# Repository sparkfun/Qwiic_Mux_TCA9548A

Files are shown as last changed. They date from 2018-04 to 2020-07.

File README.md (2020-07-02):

SparkFun Qwiic Mux Breakout - 8 Channel (TCA9548A)
========================================

SparkFun Qwiic Mux Breakout - 8 Channel (TCA9548A)

[*SparkFun Qwiic Mux Breakout - 8 Channel (TCA9548A) (BOB-16784)*](https://www.sparkfun.com/products/16784)

The Qwiic Mux Breakout enables communication with multiple I2C devices that have the same address and gets them all talking on the same bus! The Qwiic Mux also has eight configurable addresses of its own, allowing for up to 64 I2C buses on a connection. To make it even easier to use this multiplexer, all communication is enacted exclusively via I2C, utilizing our handy Qwiic system.

Repository Contents
-------------------

* **/Firmware** - Example code 
* **/Hardware** - Eagle design files (.brd, .sch)
* **/Production** - Production panel files (.brd)

Documentation
--------------
* **[Hookup Guide](https://learn.sparkfun.com/tutorials/qwiic-mux-hookup-guide)** - Basic hookup guide for the SparkFun Qwiic Mux TCA9548A.

Product Versions
----------------
* [BOB-16784](https://www.sparkfun.com/products/16784) - Version 1.1 (added pass-through Qwiic connector)
* [BOB-14685](https://www.sparkfun.com/products/14685)- SparkFun red version with TCA9548A
* [SPX-14293](https://www.sparkfun.com/products/14293)- SparkX version with PCA9548A

License Information
-------------------

This product is _**open source**_! 

Please review the LICENSE.md file for license information. 

If you have any questions or concerns on licensing, please contact techsupport@sparkfun.com.

Distributed as-is; no warranty is given.

- Your friends at SparkFun.

_<COLLABORATION CREDIT>_

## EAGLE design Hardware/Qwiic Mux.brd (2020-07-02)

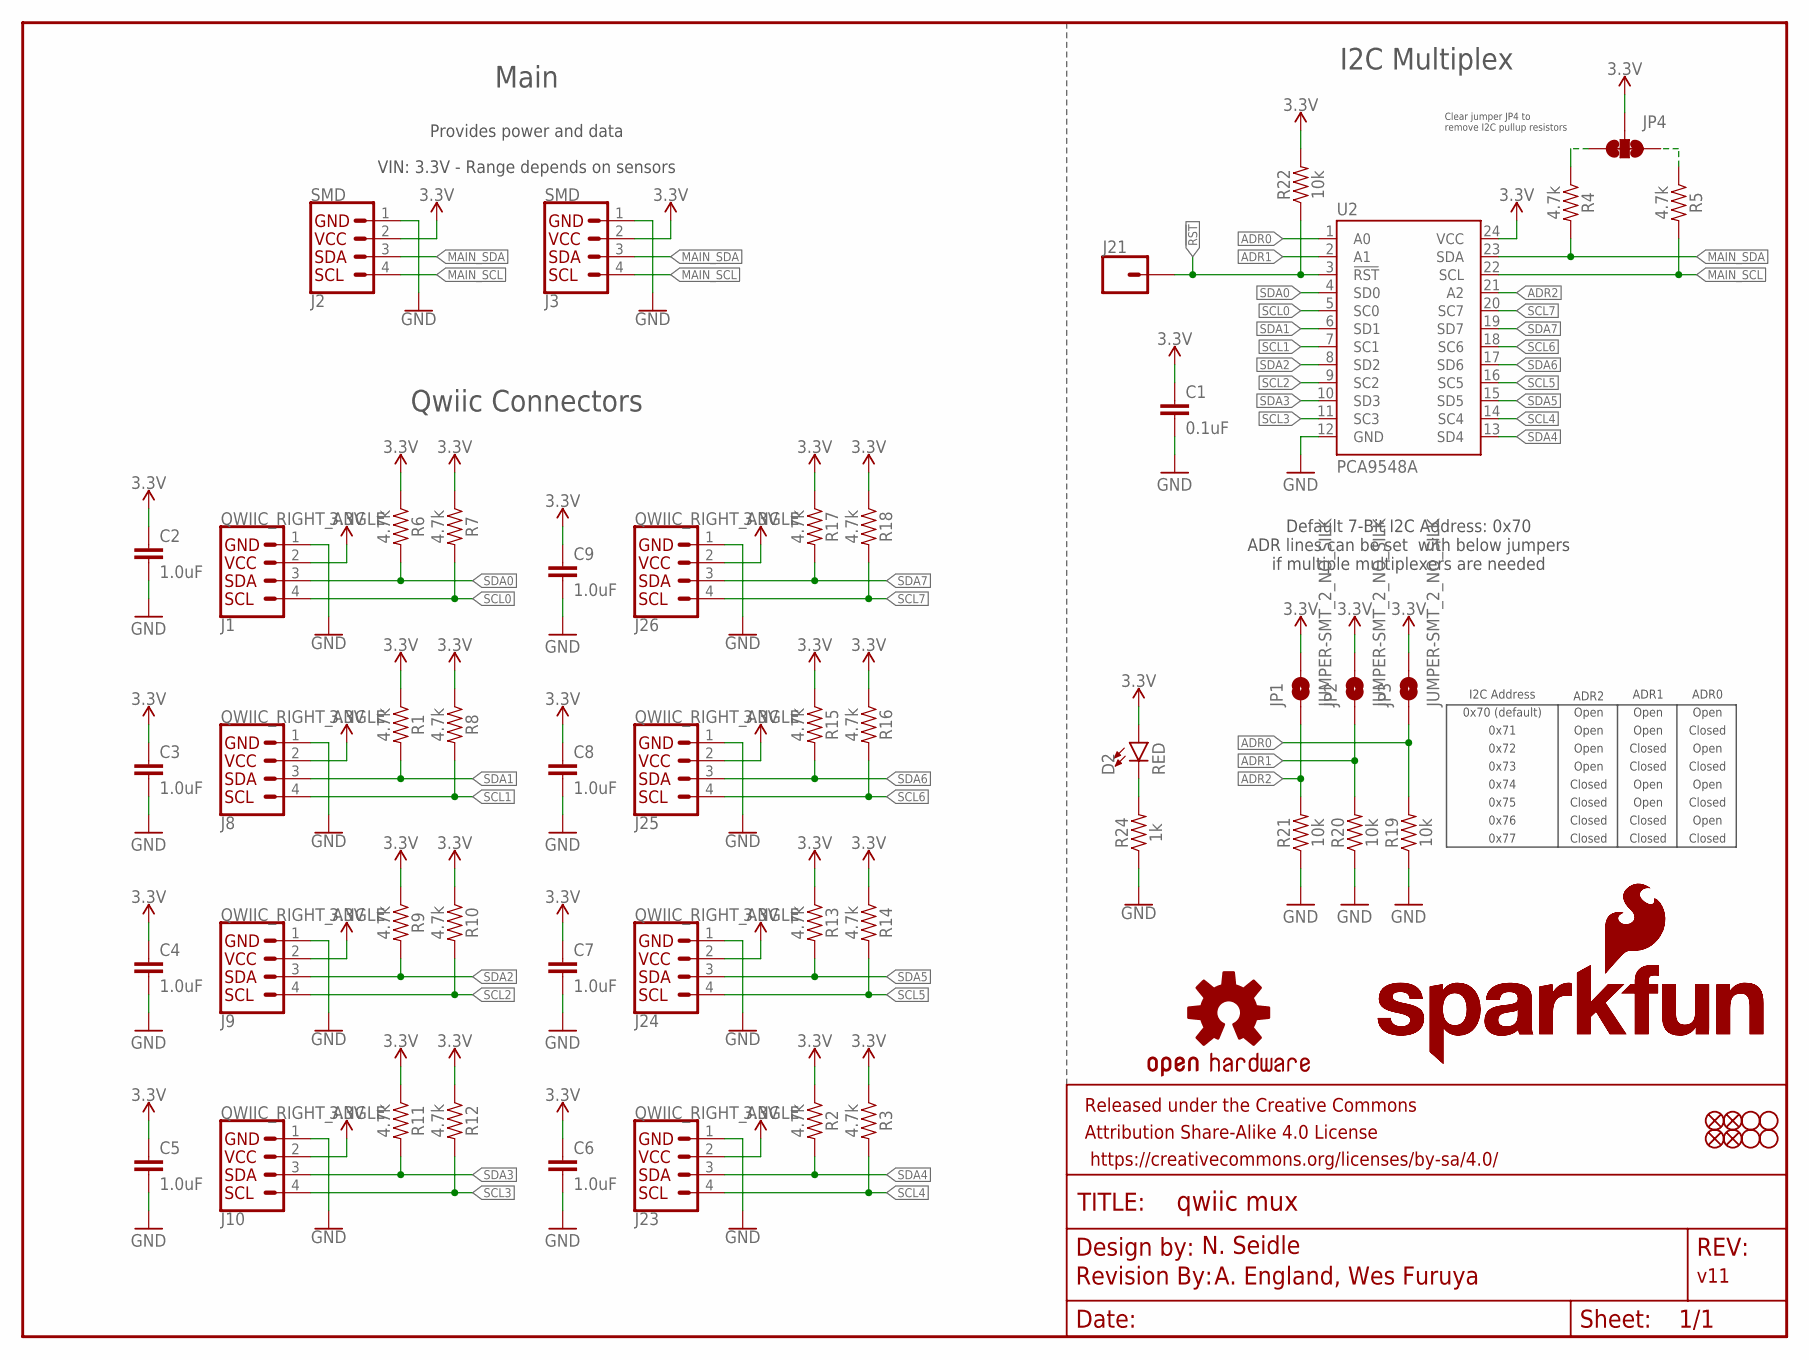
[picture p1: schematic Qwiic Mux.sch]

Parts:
C1: 0.1uF; 0603
C2, C3, C4, C5, C6, C7, C8, C9: 1.0uF; 0603
D2: RED; LED-0603
FD1, FD2, FD3, FD4: FIDUCIAL1X2; FIDUCIAL-1X2
FRAME1: FRAME-LETTER; CREATIVE_COMMONS
H1, H2, H3, H4: STAND-OFF
J1, J8, J9, J10, J23, J24, J25, J26: QWIIC_RIGHT_ANGLE; JST04_1MM_RA
J2, J3: SMD; 1X04_1MM_RA
J21: CONN_01PTH_NO_SILK_YES_STOP; 1X01_NO_SILK
JP1, JP2, JP3: JUMPER-SMT_2_NO_SILK; SMT-JUMPER_2_NO_SILK
JP4: JUMPER-SMT_3_2-NC_TRACE_SILK; SMT-JUMPER_3_2-NC_TRACE_SILK
LOGO1: OSHW-LOGOMINI; OSHW-LOGO-MINI
LOGO2: REVISION
R1, R2, R3, R4, R5, R6, R7, R8, R9, R10, R11, R12, R13, R14, R15, R16, R17, R18: 4.7k; 0603
R19, R20, R21, R22: 10k; 0603
R24: 1k; 0603
U2: PCA9548A; TSSOP28
U$1, U$2: SFE_LOGO_NAME_FLAME.1_INCH; SFE_LOGO_NAME_FLAME_.1

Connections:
3.3V: C1.1, C2.1, C3.1, C4.1, C5.1, C6.1, C7.1, C8.1, C9.1, D2.A, J1.2, J2.2 (VCC), J3.2 (VCC), J8.2, J9.2, J10.2, J23.2, J24.2, J25.2, J26.2, JP1.2, JP2.2, JP3.2, JP4.2, R1.1, R2.1, R3.1, R6.1, R7.1, R8.1, R9.1, R10.1, R11.1, R12.1, R13.1, R14.1, R15.1, R16.1, R17.1, R18.1, R22.2, U2.24 (VCC)
!RST: J21.1, R22.1, U2.3 (!RST)
ADR0: JP3.1, R19.2, U2.1 (A0)
ADR1: JP2.1, R20.2, U2.2 (A1)
ADR2: JP1.1, R21.2, U2.21 (A2)
GND: C1.2, C2.2, C3.2, C4.2, C5.2, C6.2, C7.2, C8.2, C9.2, J1.1, J2.1 (GND), J3.1 (GND), J8.1, J9.1, J10.1, J23.1, J24.1, J25.1, J26.1, R19.1, R20.1, R21.1, R24.1, U2.12 (GND)
MAIN_SCL: J2.4 (SCL), J3.4 (SCL), R5.2, U2.22 (SCL)
MAIN_SDA: J2.3 (SDA), J3.3 (SDA), R4.2, U2.23 (SDA)
unnamed: D2.C, R24.2
unnamed: JP4.3, R4.1
unnamed: JP4.1, R5.1
SCL0: J1.4, R7.2, U2.5 (SC0)
SCL1: J8.4, R8.2, U2.7 (SC1)
SCL2: J9.4, R10.2, U2.9 (SC2)
SCL3: J10.4, R12.2, U2.11 (SC3)
SCL4: J23.4, R3.2, U2.14 (SC4)
SCL5: J24.4, R14.2, U2.16 (SC5)
SCL6: J25.4, R16.2, U2.18 (SC6)
SCL7: J26.4, R18.2, U2.20 (SC7)
SDA0: J1.3, R6.2, U2.4 (SD0)
SDA1: J8.3, R1.2, U2.6 (SD1)
SDA2: J9.3, R9.2, U2.8 (SD2)
SDA3: J10.3, R11.2, U2.10 (SD3)
SDA4: J23.3, R2.2, U2.13 (SD4)
SDA5: J24.3, R13.2, U2.15 (SD5)
SDA6: J25.3, R15.2, U2.17 (SD6)
SDA7: J26.3, R17.2, U2.19 (SD7)

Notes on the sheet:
N. Seidle
v11
Qwiic Connectors
Default 7-Bit I2C Address: 0x70 ADR lines can be set with below jumpers if multiple multiplexers are needed
Main
Provides power and data
VIN: 3.3V - Range depends on sensors
I2C Multiplex
I2C Address
ADR0
ADR1
ADR2
Open
Closed
0x70 (default)
0x71
0x72
0x73
0x74
0x75
0x76
0x77
A. England, Wes Furuya
Clear jumper JP4 to remove I2C pullup resistors

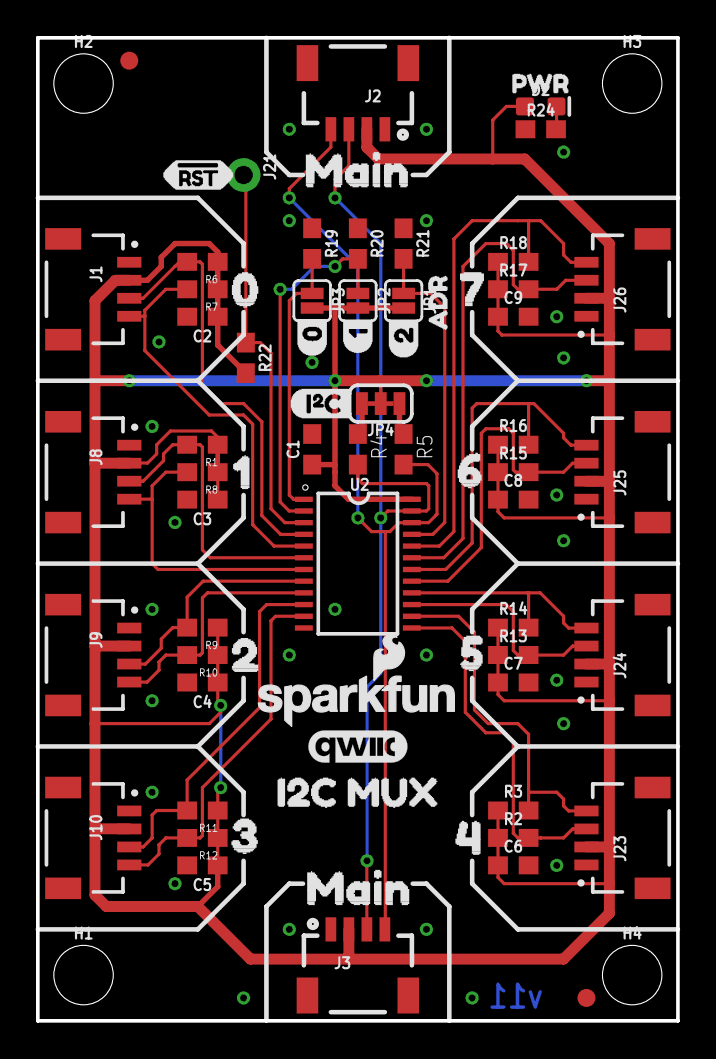
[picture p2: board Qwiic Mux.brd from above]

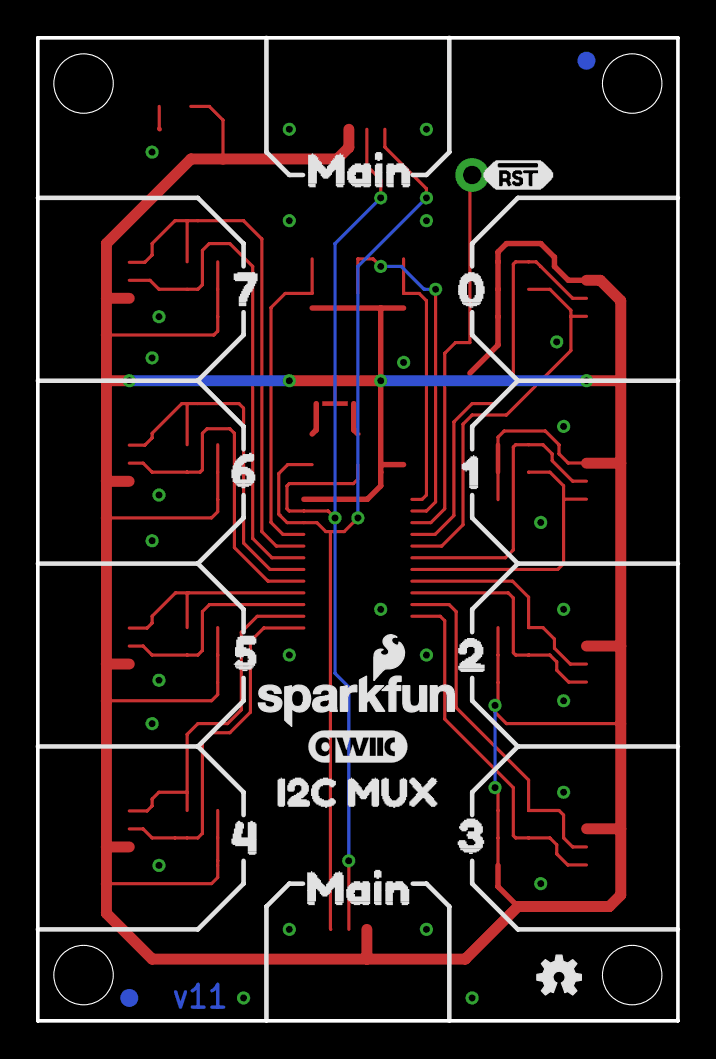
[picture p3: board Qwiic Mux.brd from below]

Board: 2 copper layers, 35.6 x 54.6 mm, 94 parts (17 on the bottom side), 27 nets.

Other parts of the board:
U$3, U$15: I2C_MUX8
U$4, U$36: QWIIC_5.5MM
U$5: 04
U$6, U$12: 00
U$7, U$18: 11
U$8, U$19: 22
U$9, U$20: 33
U$10, U$21: 44
U$11, U$22: 55
U$13, U$24: 77
U$14, U$26: !RST_I
U$16, U$25, U$27, U$28: MAIN0
U$17, U$23: 61
U$31: PWR_TO
U$32: 15
U$33: 26
U$34: ADR3
U$35: I#C6

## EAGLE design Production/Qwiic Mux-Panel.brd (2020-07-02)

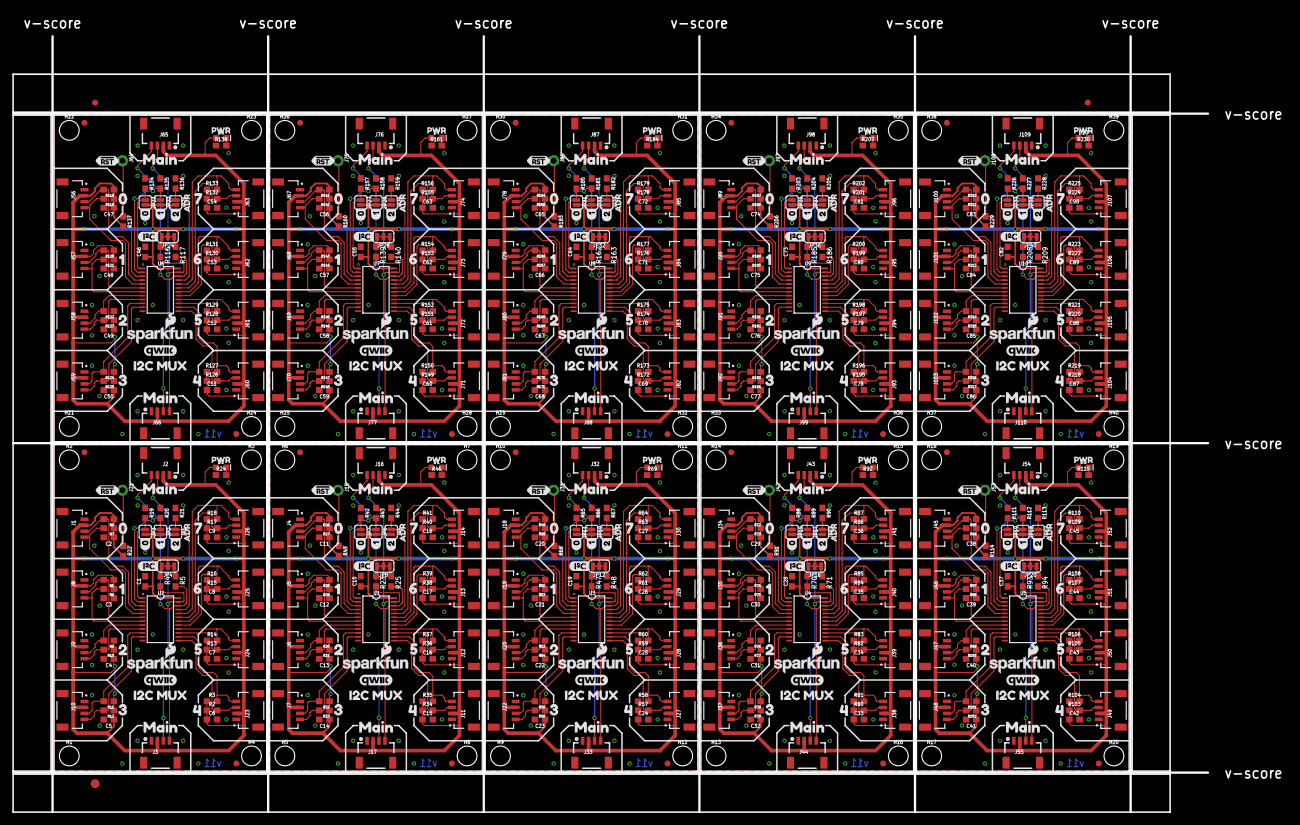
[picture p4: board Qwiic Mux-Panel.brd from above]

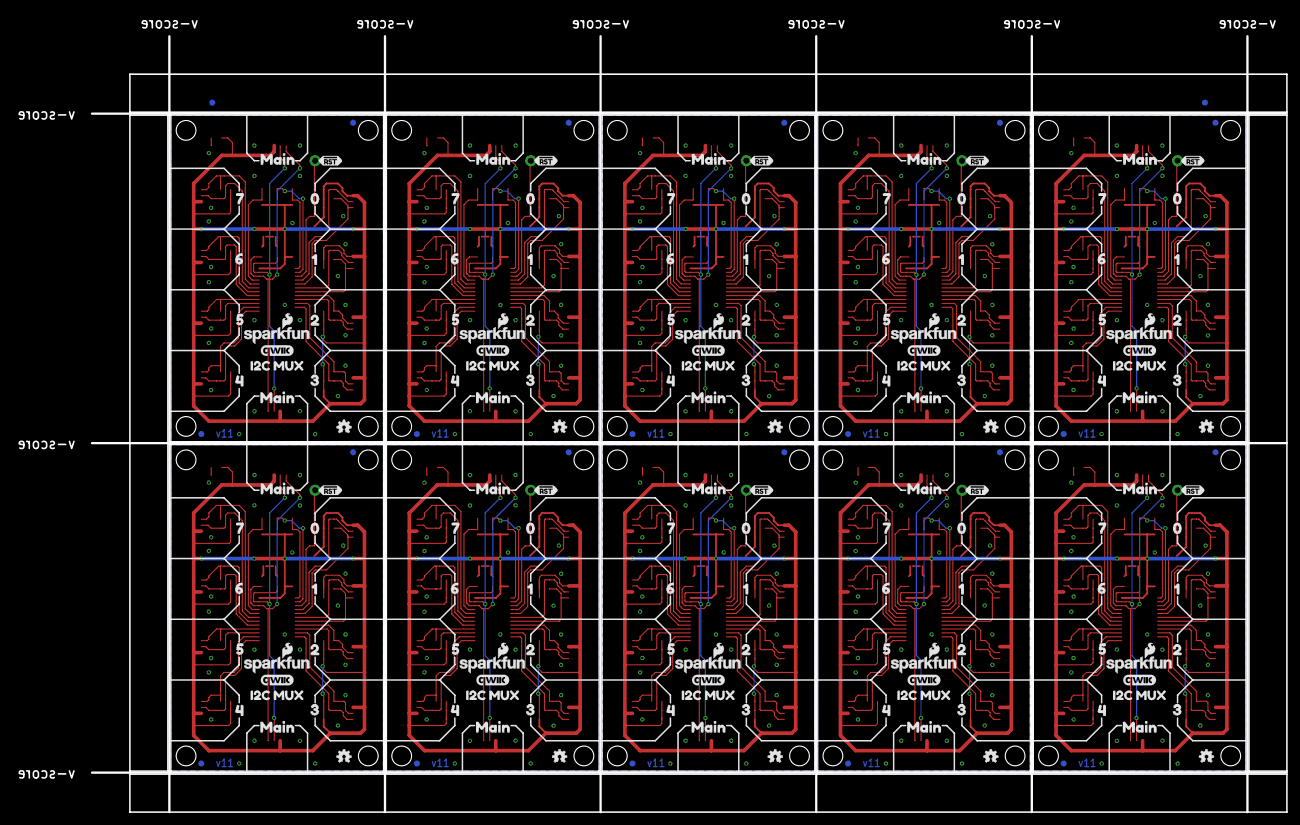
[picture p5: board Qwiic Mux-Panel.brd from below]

Board: 2 copper layers, 199.9 x 129.8 mm, 935 parts (172 on the bottom side), 270 nets.

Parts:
C1, C10, C19, C28, C37, C46, C55, C64, C73, C82: 0.1uF; 0603
C2, C3, C4, C5, C6, C7, C8, C9, C11, C12, C13, C14, C15, C16, C17, C18, C20, C21, C22, C23, C24, C25, C26, C27, C29, C30, C31, C32, C33, C34, C35, C36, C38, C39, C40, C41, C42, C43, C44, C45, C47, C48, C49, C50, C51, C52, C53, C54, C56, C57, C58, C59, C60, C61, C62, C63, C65, C66, C67, C68, C69, C70, C71, C72, C74, C75, C76, C77, C78, C79, C80, C81, C83, C84, C85, C86, C87, C88, C89, C90: 1.0uF; 0603
D1, D2, D3, D4, D5, D6, D7, D8, D9, D10: RED; LED-0603
E$1, E$2, E$3, E$4: FIDUCIAL-1X2
E$5: FIDUCIAL-1.5X3
FD1, FD2, FD3, FD4, FD5, FD6, FD7, FD8, FD9, FD10, FD11, FD12, FD13, FD14, FD15, FD16, FD17, FD18, FD19, FD20, FD21, FD22, FD23, FD24, FD25, FD26, FD27, FD28, FD29, FD30, FD31, FD32, FD33, FD34, FD35, FD36, FD37, FD38, FD39, FD40: FIDUCIAL1X2; FIDUCIAL-1X2
H1, H2, H3, H4, H5, H6, H7, H8, H9, H10, H11, H12, H13, H14, H15, H16, H17, H18, H19, H20, H21, H22, H23, H24, H25, H26, H27, H28, H29, H30, H31, H32, H33, H34, H35, H36, H37, H38, H39, H40: STAND-OFF
J1, J4, J5, J6, J7, J8, J9, J10, J11, J12, J13, J14, J18, J19, J20, J22, J23, J24, J25, J26, J27, J28, J29, J30, J34, J35, J36, J37, J38, J39, J40, J41, J45, J46, J47, J48, J49, J50, J51, J52, J56, J57, J58, J59, J60, J61, J62, J63, J67, J68, J69, J70, J71, J72, J73, J74, J78, J79, J80, J81, J82, J83, J84, J85, J89, J90, J91, J92, J93, J94, J95, J96, J100, J101, J102, J103, J104, J105, J106, J107: QWIIC_RIGHT_ANGLE; JST04_1MM_RA
J2, J3, J16, J17, J32, J33, J43, J44, J54, J55, J65, J66, J76, J77, J87, J88, J98, J99, J109, J110: SMD; 1X04_1MM_RA
J15, J21, J31, J42, J53, J64, J75, J86, J97, J108: 1X01_NO_SILK
JP1, JP2, JP3, JP5, JP6, JP7, JP9, JP10, JP11, JP13, JP14, JP15, JP17, JP18, JP19, JP21, JP22, JP23, JP25, JP26, JP27, JP29, JP30, JP31, JP33, JP34, JP35, JP37, JP38, JP39: JUMPER-SMT_2_NO_SILK; SMT-JUMPER_2_NO_SILK
JP4, JP8, JP12, JP16, JP20, JP24, JP28, JP32, JP36, JP40: JUMPER-SMT_3_2-NC_TRACE_SILK; SMT-JUMPER_3_2-NC_TRACE_SILK
LOGO1, LOGO3, LOGO5, LOGO7, LOGO9, LOGO11, LOGO13, LOGO15, LOGO17, LOGO19: OSHW-LOGOMINI; OSHW-LOGO-MINI
LOGO2, LOGO4, LOGO6, LOGO8, LOGO10, LOGO12, LOGO14, LOGO16, LOGO18, LOGO20: REVISION
R1, R2, R3, R4, R5, R6, R7, R8, R9, R10, R11, R12, R13, R14, R15, R16, R17, R18, R23, R25, R26, R27, R28, R29, R30, R31, R32, R33, R34, R35, R36, R37, R38, R39, R40, R41, R47, R48, R49, R50, R51, R52, R53, R54, R55, R56, R57, R58, R59, R60, R61, R62, R63, R64, R70, R71, R72, R73, R74, R75, R76, R77, R78, R79, R80, R81, R82, R83, R84, R85, R86, R87, R93, R94, R95, R96, R97, R98, R99, R100, R101, R102, R103, R104, R105, R106, R107, R108, R109, R110, R116, R117, R118, R119, R120, R121, R122, R123, R124, R125, R126, R127, R128, R129, R130, R131, R132, R133, R139, R140, R141, R142, R143, R144, R145, R146, R147, R148, R149, R150, R151, R152, R153, R154, R155, R156, R162, R163, R164, R165, R166, R167, R168, R169, R170, R171, R172, R173, R174, R175, R176, R177, R178, R179, R185, R186, R187, R188, R189, R190, R191, R192, R193, R194, R195, R196, R197, R198, R199, R200, R201, R202, R208, R209, R210, R211, R212, R213, R214, R215, R216, R217, R218, R219, R220, R221, R222, R223, R224, R225: 4.7k; 0603
R19, R20, R21, R22, R42, R43, R44, R45, R65, R66, R67, R68, R88, R89, R90, R91, R111, R112, R113, R114, R134, R135, R136, R137, R157, R158, R159, R160, R180, R181, R182, R183, R203, R204, R205, R206, R226, R227, R228, R229: 10k; 0603
R24, R46, R69, R92, R115, R138, R161, R184, R207, R230: 1k; 0603
U1, U2, U3, U4, U5, U6, U7, U8, U9, U10: PCA9548A; TSSOP28
U$1, U$2, U$29, U$30, U$69, U$70, U$103, U$104, U$137, U$138, U$171, U$172, U$205, U$206, U$239, U$240, U$273, U$274, U$307, U$308: SFE_LOGO_NAME_FLAME.1_INCH; SFE_LOGO_NAME_FLAME_.1
U$3, U$15, U$44, U$61, U$78, U$95, U$112, U$129, U$146, U$163, U$180, U$197, U$214, U$231, U$248, U$265, U$282, U$299, U$316, U$333: I2C_MUX8
U$4, U$36, U$62, U$63, U$96, U$97, U$130, U$131, U$164, U$165, U$198, U$199, U$232, U$233, U$266, U$267, U$300, U$301, U$334, U$335: QWIIC_5.5MM
U$5, U$65, U$99, U$133, U$167, U$201, U$235, U$269, U$303, U$337: 04
U$6, U$12, U$37, U$47, U$71, U$81, U$105, U$115, U$139, U$149, U$173, U$183, U$207, U$217, U$241, U$251, U$275, U$285, U$309, U$319: 00
U$7, U$18, U$41, U$48, U$75, U$82, U$109, U$116, U$143, U$150, U$177, U$184, U$211, U$218, U$245, U$252, U$279, U$286, U$313, U$320: 11
U$8, U$19, U$42, U$49, U$76, U$83, U$110, U$117, U$144, U$151, U$178, U$185, U$212, U$219, U$246, U$253, U$280, U$287, U$314, U$321: 22
U$9, U$20, U$43, U$50, U$77, U$84, U$111, U$118, U$145, U$152, U$179, U$186, U$213, U$220, U$247, U$254, U$281, U$288, U$315, U$322: 33
U$10, U$21, U$38, U$51, U$72, U$85, U$106, U$119, U$140, U$153, U$174, U$187, U$208, U$221, U$242, U$255, U$276, U$289, U$310, U$323: 44
U$11, U$22, U$39, U$52, U$73, U$86, U$107, U$120, U$141, U$154, U$175, U$188, U$209, U$222, U$243, U$256, U$277, U$290, U$311, U$324: 55
U$13, U$24, U$40, U$54, U$74, U$88, U$108, U$122, U$142, U$156, U$176, U$190, U$210, U$224, U$244, U$258, U$278, U$292, U$312, U$326: 77
U$14, U$26, U$58, U$59, U$92, U$93, U$126, U$127, U$160, U$161, U$194, U$195, U$228, U$229, U$262, U$263, U$296, U$297, U$330, U$331: !RST_I
U$16, U$25, U$27, U$28, U$45, U$55, U$56, U$57, U$79, U$89, U$90, U$91, U$113, U$123, U$124, U$125, U$147, U$157, U$158, U$159, U$181, U$191, U$192, U$193, U$215, U$225, U$226, U$227, U$249, U$259, U$260, U$261, U$283, U$293, U$294, U$295, U$317, U$327, U$328, U$329: MAIN0
U$17, U$23, U$46, U$53, U$80, U$87, U$114, U$121, U$148, U$155, U$182, U$189, U$216, U$223, U$250, U$257, U$284, U$291, U$318, U$325: 61
U$31, U$60, U$94, U$128, U$162, U$196, U$230, U$264, U$298, U$332: PWR_TO
U$32, U$66, U$100, U$134, U$168, U$202, U$236, U$270, U$304, U$338: 15
U$33, U$67, U$101, U$135, U$169, U$203, U$237, U$271, U$305, U$339: 26
U$34, U$68, U$102, U$136, U$170, U$204, U$238, U$272, U$306, U$340: ADR3
U$35, U$64, U$98, U$132, U$166, U$200, U$234, U$268, U$302, U$336: I#C6

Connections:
3.3V: C1.1, C2.1, C3.1, C4.1, C5.1, C6.1, C7.1, C8.1, C9.1, D2.A, J1.2, J2.2, J3.2, J8.2, J9.2, J10.2, J23.2, J24.2, J25.2, J26.2, JP1.2, JP2.2, JP3.2, JP4.2, R1.1, R2.1, R3.1, R6.1, R7.1, R8.1, R9.1, R10.1, R11.1, R12.1, R13.1, R14.1, R15.1, R16.1, R17.1, R18.1, R22.2, U2.24
3.3V1: C10.1, C11.1, C12.1, C13.1, C14.1, C15.1, C16.1, C17.1, C18.1, D1.A, J4.2, J5.2, J6.2, J7.2, J11.2, J12.2, J13.2, J14.2, J16.2, J17.2, JP5.2, JP6.2, JP7.2, JP8.2, R26.1, R27.1, R28.1, R29.1, R30.1, R31.1, R32.1, R33.1, R34.1, R35.1, R36.1, R37.1, R38.1, R39.1, R40.1, R41.1, R45.2, U1.24
3.3V2: C19.1, C20.1, C21.1, C22.1, C23.1, C24.1, C25.1, C26.1, C27.1, D3.A, J18.2, J19.2, J20.2, J22.2, J27.2, J28.2, J29.2, J30.2, J32.2, J33.2, JP9.2, JP10.2, JP11.2, JP12.2, R49.1, R50.1, R51.1, R52.1, R53.1, R54.1, R55.1, R56.1, R57.1, R58.1, R59.1, R60.1, R61.1, R62.1, R63.1, R64.1, R68.2, U3.24
3.3V3: C28.1, C29.1, C30.1, C31.1, C32.1, C33.1, C34.1, C35.1, C36.1, D4.A, J34.2, J35.2, J36.2, J37.2, J38.2, J39.2, J40.2, J41.2, J43.2, J44.2, JP13.2, JP14.2, JP15.2, JP16.2, R72.1, R73.1, R74.1, R75.1, R76.1, R77.1, R78.1, R79.1, R80.1, R81.1, R82.1, R83.1, R84.1, R85.1, R86.1, R87.1, R91.2, U4.24
3.3V4: C37.1, C38.1, C39.1, C40.1, C41.1, C42.1, C43.1, C44.1, C45.1, D5.A, J45.2, J46.2, J47.2, J48.2, J49.2, J50.2, J51.2, J52.2, J54.2, J55.2, JP17.2, JP18.2, JP19.2, JP20.2, R95.1, R96.1, R97.1, R98.1, R99.1, R100.1, R101.1, R102.1, R103.1, R104.1, R105.1, R106.1, R107.1, R108.1, R109.1, R110.1, R114.2, U5.24
3.3V5: C46.1, C47.1, C48.1, C49.1, C50.1, C51.1, C52.1, C53.1, C54.1, D6.A, J56.2, J57.2, J58.2, J59.2, J60.2, J61.2, J62.2, J63.2, J65.2, J66.2, JP21.2, JP22.2, JP23.2, JP24.2, R118.1, R119.1, R120.1, R121.1, R122.1, R123.1, R124.1, R125.1, R126.1, R127.1, R128.1, R129.1, R130.1, R131.1, R132.1, R133.1, R137.2, U6.24
3.3V6: C55.1, C56.1, C57.1, C58.1, C59.1, C60.1, C61.1, C62.1, C63.1, D7.A, J67.2, J68.2, J69.2, J70.2, J71.2, J72.2, J73.2, J74.2, J76.2, J77.2, JP25.2, JP26.2, JP27.2, JP28.2, R141.1, R142.1, R143.1, R144.1, R145.1, R146.1, R147.1, R148.1, R149.1, R150.1, R151.1, R152.1, R153.1, R154.1, R155.1, R156.1, R160.2, U7.24
3.3V7: C64.1, C65.1, C66.1, C67.1, C68.1, C69.1, C70.1, C71.1, C72.1, D8.A, J78.2, J79.2, J80.2, J81.2, J82.2, J83.2, J84.2, J85.2, J87.2, J88.2, JP29.2, JP30.2, JP31.2, JP32.2, R164.1, R165.1, R166.1, R167.1, R168.1, R169.1, R170.1, R171.1, R172.1, R173.1, R174.1, R175.1, R176.1, R177.1, R178.1, R179.1, R183.2, U8.24
3.3V8: C73.1, C74.1, C75.1, C76.1, C77.1, C78.1, C79.1, C80.1, C81.1, D9.A, J89.2, J90.2, J91.2, J92.2, J93.2, J94.2, J95.2, J96.2, J98.2, J99.2, JP33.2, JP34.2, JP35.2, JP36.2, R187.1, R188.1, R189.1, R190.1, R191.1, R192.1, R193.1, R194.1, R195.1, R196.1, R197.1, R198.1, R199.1, R200.1, R201.1, R202.1, R206.2, U9.24
3.3V9: C82.1, C83.1, C84.1, C85.1, C86.1, C87.1, C88.1, C89.1, C90.1, D10.A, J100.2, J101.2, J102.2, J103.2, J104.2, J105.2, J106.2, J107.2, J109.2, J110.2, JP37.2, JP38.2, JP39.2, JP40.2, R210.1, R211.1, R212.1, R213.1, R214.1, R215.1, R216.1, R217.1, R218.1, R219.1, R220.1, R221.1, R222.1, R223.1, R224.1, R225.1, R229.2, U10.24
!RST: J21.1, R22.1, U2.3
!RST1: J15.1, R45.1, U1.3
!RST2: J31.1, R68.1, U3.3
!RST3: J42.1, R91.1, U4.3
!RST4: J53.1, R114.1, U5.3
!RST5: J64.1, R137.1, U6.3
!RST6: J75.1, R160.1, U7.3
!RST7: J86.1, R183.1, U8.3
!RST8: J97.1, R206.1, U9.3
!RST9: J108.1, R229.1, U10.3
ADR0: JP3.1, R19.2, U2.1
ADR1: JP2.1, R20.2, U2.2
ADR2: JP1.1, R21.2, U2.21
ADR3: JP6.1, R43.2, U1.2
ADR4: JP7.1, R42.2, U1.1
ADR5: JP5.1, R44.2, U1.21
ADR6: JP10.1, R66.2, U3.2
ADR7: JP11.1, R65.2, U3.1
ADR8: JP9.1, R67.2, U3.21
ADR9: JP14.1, R89.2, U4.2
ADR10: JP15.1, R88.2, U4.1
ADR11: JP13.1, R90.2, U4.21
ADR12: JP18.1, R112.2, U5.2
ADR13: JP19.1, R111.2, U5.1
ADR14: JP17.1, R113.2, U5.21
ADR15: JP22.1, R135.2, U6.2
ADR16: JP23.1, R134.2, U6.1
ADR17: JP21.1, R136.2, U6.21
ADR18: JP26.1, R158.2, U7.2
ADR19: JP27.1, R157.2, U7.1
ADR20: JP25.1, R159.2, U7.21
ADR21: JP30.1, R181.2, U8.2
ADR22: JP31.1, R180.2, U8.1
ADR23: JP29.1, R182.2, U8.21
ADR24: JP34.1, R204.2, U9.2
ADR25: JP35.1, R203.2, U9.1
ADR26: JP33.1, R205.2, U9.21
ADR27: JP38.1, R227.2, U10.2
ADR28: JP39.1, R226.2, U10.1
ADR29: JP37.1, R228.2, U10.21
GND: C1.2, C2.2, C3.2, C4.2, C5.2, C6.2, C7.2, C8.2, C9.2, J1.1, J2.1, J3.1, J8.1, J9.1, J10.1, J23.1, J24.1, J25.1, J26.1, R19.1, R20.1, R21.1, R24.1, U2.12
GND1: C10.2, C11.2, C12.2, C13.2, C14.2, C15.2, C16.2, C17.2, C18.2, J4.1, J5.1, J6.1, J7.1, J11.1, J12.1, J13.1, J14.1, J16.1, J17.1, R42.1, R43.1, R44.1, R46.1, U1.12
GND2: C19.2, C20.2, C21.2, C22.2, C23.2, C24.2, C25.2, C26.2, C27.2, J18.1, J19.1, J20.1, J22.1, J27.1, J28.1, J29.1, J30.1, J32.1, J33.1, R65.1, R66.1, R67.1, R69.1, U3.12
GND3: C28.2, C29.2, C30.2, C31.2, C32.2, C33.2, C34.2, C35.2, C36.2, J34.1, J35.1, J36.1, J37.1, J38.1, J39.1, J40.1, J41.1, J43.1, J44.1, R88.1, R89.1, R90.1, R92.1, U4.12
GND4: C37.2, C38.2, C39.2, C40.2, C41.2, C42.2, C43.2, C44.2, C45.2, J45.1, J46.1, J47.1, J48.1, J49.1, J50.1, J51.1, J52.1, J54.1, J55.1, R111.1, R112.1, R113.1, R115.1, U5.12
GND5: C46.2, C47.2, C48.2, C49.2, C50.2, C51.2, C52.2, C53.2, C54.2, J56.1, J57.1, J58.1, J59.1, J60.1, J61.1, J62.1, J63.1, J65.1, J66.1, R134.1, R135.1, R136.1, R138.1, U6.12
GND6: C55.2, C56.2, C57.2, C58.2, C59.2, C60.2, C61.2, C62.2, C63.2, J67.1, J68.1, J69.1, J70.1, J71.1, J72.1, J73.1, J74.1, J76.1, J77.1, R157.1, R158.1, R159.1, R161.1, U7.12
GND7: C64.2, C65.2, C66.2, C67.2, C68.2, C69.2, C70.2, C71.2, C72.2, J78.1, J79.1, J80.1, J81.1, J82.1, J83.1, J84.1, J85.1, J87.1, J88.1, R180.1, R181.1, R182.1, R184.1, U8.12
GND8: C73.2, C74.2, C75.2, C76.2, C77.2, C78.2, C79.2, C80.2, C81.2, J89.1, J90.1, J91.1, J92.1, J93.1, J94.1, J95.1, J96.1, J98.1, J99.1, R203.1, R204.1, R205.1, R207.1, U9.12
GND9: C82.2, C83.2, C84.2, C85.2, C86.2, C87.2, C88.2, C89.2, C90.2, J100.1, J101.1, J102.1, J103.1, J104.1, J105.1, J106.1, J107.1, J109.1, J110.1, R226.1, R227.1, R228.1, R230.1, U10.12
MAIN_SCL: J2.4, J3.4, R5.2, U2.22
MAIN_SCL1: J16.4, J17.4, R25.2, U1.22
MAIN_SCL2: J32.4, J33.4, R48.2, U3.22
MAIN_SCL3: J43.4, J44.4, R71.2, U4.22
MAIN_SCL4: J54.4, J55.4, R94.2, U5.22
MAIN_SCL5: J65.4, J66.4, R117.2, U6.22
MAIN_SCL6: J76.4, J77.4, R140.2, U7.22
MAIN_SCL7: J87.4, J88.4, R163.2, U8.22
MAIN_SCL8: J98.4, J99.4, R186.2, U9.22
MAIN_SCL9: J109.4, J110.4, R209.2, U10.22
MAIN_SDA: J2.3, J3.3, R4.2, U2.23
MAIN_SDA1: J16.3, J17.3, R23.2, U1.23
MAIN_SDA2: J32.3, J33.3, R47.2, U3.23
MAIN_SDA3: J43.3, J44.3, R70.2, U4.23
MAIN_SDA4: J54.3, J55.3, R93.2, U5.23
MAIN_SDA5: J65.3, J66.3, R116.2, U6.23
MAIN_SDA6: J76.3, J77.3, R139.2, U7.23
MAIN_SDA7: J87.3, J88.3, R162.2, U8.23
MAIN_SDA8: J98.3, J99.3, R185.2, U9.23
MAIN_SDA9: J109.3, J110.3, R208.2, U10.23
unnamed: D2.C, R24.2
unnamed: JP4.3, R4.1
unnamed: JP4.1, R5.1
unnamed: D1.C, R46.2
unnamed: JP8.3, R23.1
unnamed: JP8.1, R25.1
unnamed: D3.C, R69.2
unnamed: JP12.3, R47.1
unnamed: JP12.1, R48.1
unnamed: D4.C, R92.2
unnamed: JP16.3, R70.1
unnamed: JP16.1, R71.1
unnamed: D5.C, R115.2
unnamed: JP20.3, R93.1
unnamed: JP20.1, R94.1
unnamed: D6.C, R138.2
unnamed: JP24.3, R116.1
unnamed: JP24.1, R117.1
unnamed: D7.C, R161.2
unnamed: JP28.3, R139.1
unnamed: JP28.1, R140.1
unnamed: D8.C, R184.2
unnamed: JP32.3, R162.1
unnamed: JP32.1, R163.1
unnamed: D9.C, R207.2
unnamed: JP36.3, R185.1
unnamed: JP36.1, R186.1
unnamed: D10.C, R230.2
unnamed: JP40.3, R208.1
unnamed: JP40.1, R209.1
SCL0: J1.4, R7.2, U2.5
SCL1: J8.4, R8.2, U2.7
SCL2: J9.4, R10.2, U2.9
SCL3: J10.4, R12.2, U2.11
SCL4: J23.4, R3.2, U2.14
SCL5: J24.4, R14.2, U2.16
SCL6: J25.4, R16.2, U2.18
SCL7: J26.4, R18.2, U2.20
SCL8: J4.4, R27.2, U1.5
SCL9: J5.4, R29.2, U1.7
SCL10: J7.4, R33.2, U1.11
SCL11: J11.4, R35.2, U1.14
SCL12: J12.4, R37.2, U1.16
SCL13: J13.4, R39.2, U1.18
SCL14: J14.4, R41.2, U1.20
SCL15: J6.4, R31.2, U1.9
SCL16: J18.4, R50.2, U3.5
SCL17: J19.4, R52.2, U3.7
SCL18: J22.4, R56.2, U3.11
SCL19: J27.4, R58.2, U3.14
SCL20: J28.4, R60.2, U3.16
SCL21: J29.4, R62.2, U3.18
SCL22: J30.4, R64.2, U3.20
SCL23: J20.4, R54.2, U3.9
SCL24: J34.4, R73.2, U4.5
SCL25: J35.4, R75.2, U4.7
SCL26: J37.4, R79.2, U4.11
SCL27: J38.4, R81.2, U4.14
SCL28: J39.4, R83.2, U4.16
SCL29: J40.4, R85.2, U4.18
SCL30: J41.4, R87.2, U4.20
SCL31: J36.4, R77.2, U4.9
SCL32: J45.4, R96.2, U5.5
SCL33: J46.4, R98.2, U5.7
SCL34: J48.4, R102.2, U5.11
SCL35: J49.4, R104.2, U5.14
SCL36: J50.4, R106.2, U5.16
SCL37: J51.4, R108.2, U5.18
SCL38: J52.4, R110.2, U5.20
SCL39: J47.4, R100.2, U5.9
SCL40: J56.4, R119.2, U6.5
SCL41: J57.4, R121.2, U6.7
SCL42: J59.4, R125.2, U6.11
SCL43: J60.4, R127.2, U6.14
SCL44: J61.4, R129.2, U6.16
SCL45: J62.4, R131.2, U6.18
SCL46: J63.4, R133.2, U6.20
SCL47: J58.4, R123.2, U6.9
SCL48: J67.4, R142.2, U7.5
SCL49: J68.4, R144.2, U7.7
SCL50: J70.4, R148.2, U7.11
SCL51: J71.4, R150.2, U7.14
SCL52: J72.4, R152.2, U7.16
SCL53: J73.4, R154.2, U7.18
SCL54: J74.4, R156.2, U7.20
SCL55: J69.4, R146.2, U7.9
SCL56: J78.4, R165.2, U8.5
SCL57: J79.4, R167.2, U8.7
SCL58: J81.4, R171.2, U8.11
SCL59: J82.4, R173.2, U8.14
SCL60: J83.4, R175.2, U8.16
SCL61: J84.4, R177.2, U8.18
SCL62: J85.4, R179.2, U8.20
SCL63: J80.4, R169.2, U8.9
SCL64: J89.4, R188.2, U9.5
SCL65: J90.4, R190.2, U9.7
SCL66: J92.4, R194.2, U9.11
SCL67: J93.4, R196.2, U9.14
SCL68: J94.4, R198.2, U9.16
SCL69: J95.4, R200.2, U9.18
SCL70: J96.4, R202.2, U9.20
SCL71: J91.4, R192.2, U9.9
SCL72: J100.4, R211.2, U10.5
SCL73: J101.4, R213.2, U10.7
SCL74: J103.4, R217.2, U10.11
SCL75: J104.4, R219.2, U10.14
SCL76: J105.4, R221.2, U10.16
SCL77: J106.4, R223.2, U10.18
SCL78: J107.4, R225.2, U10.20
SCL79: J102.4, R215.2, U10.9
SDA0: J1.3, R6.2, U2.4
SDA1: J8.3, R1.2, U2.6
SDA2: J9.3, R9.2, U2.8
SDA3: J10.3, R11.2, U2.10
SDA4: J23.3, R2.2, U2.13
SDA5: J24.3, R13.2, U2.15
SDA6: J25.3, R15.2, U2.17
SDA7: J26.3, R17.2, U2.19
SDA8: J4.3, R26.2, U1.4
SDA9: J5.3, R28.2, U1.6
SDA10: J7.3, R32.2, U1.10
SDA11: J11.3, R34.2, U1.13
SDA12: J12.3, R36.2, U1.15
SDA13: J14.3, R40.2, U1.19
SDA14: J13.3, R38.2, U1.17
SDA15: J6.3, R30.2, U1.8
SDA16: J18.3, R49.2, U3.4
SDA17: J19.3, R51.2, U3.6
SDA18: J22.3, R55.2, U3.10
SDA19: J27.3, R57.2, U3.13
SDA20: J28.3, R59.2, U3.15
SDA21: J30.3, R63.2, U3.19
SDA22: J29.3, R61.2, U3.17
SDA23: J20.3, R53.2, U3.8
SDA24: J34.3, R72.2, U4.4
SDA25: J35.3, R74.2, U4.6
SDA26: J37.3, R78.2, U4.10
SDA27: J38.3, R80.2, U4.13
SDA28: J39.3, R82.2, U4.15
SDA29: J41.3, R86.2, U4.19
SDA30: J40.3, R84.2, U4.17
SDA31: J36.3, R76.2, U4.8
SDA32: J45.3, R95.2, U5.4
SDA33: J46.3, R97.2, U5.6
SDA34: J48.3, R101.2, U5.10
SDA35: J49.3, R103.2, U5.13
SDA36: J50.3, R105.2, U5.15
SDA37: J52.3, R109.2, U5.19
SDA38: J51.3, R107.2, U5.17
SDA39: J47.3, R99.2, U5.8
SDA40: J56.3, R118.2, U6.4
SDA41: J57.3, R120.2, U6.6
SDA42: J59.3, R124.2, U6.10
SDA43: J60.3, R126.2, U6.13
SDA44: J61.3, R128.2, U6.15
SDA45: J63.3, R132.2, U6.19
SDA46: J62.3, R130.2, U6.17
SDA47: J58.3, R122.2, U6.8
SDA48: J67.3, R141.2, U7.4
SDA49: J68.3, R143.2, U7.6
SDA50: J70.3, R147.2, U7.10
SDA51: J71.3, R149.2, U7.13
SDA52: J72.3, R151.2, U7.15
SDA53: J74.3, R155.2, U7.19
SDA54: J73.3, R153.2, U7.17
SDA55: J69.3, R145.2, U7.8
SDA56: J78.3, R164.2, U8.4
SDA57: J79.3, R166.2, U8.6
SDA58: J81.3, R170.2, U8.10
SDA59: J82.3, R172.2, U8.13
SDA60: J83.3, R174.2, U8.15
SDA61: J85.3, R178.2, U8.19
SDA62: J84.3, R176.2, U8.17
SDA63: J80.3, R168.2, U8.8
SDA64: J89.3, R187.2, U9.4
SDA65: J90.3, R189.2, U9.6
SDA66: J92.3, R193.2, U9.10
SDA67: J93.3, R195.2, U9.13
SDA68: J94.3, R197.2, U9.15
SDA69: J96.3, R201.2, U9.19
SDA70: J95.3, R199.2, U9.17
SDA71: J91.3, R191.2, U9.8
SDA72: J100.3, R210.2, U10.4
SDA73: J101.3, R212.2, U10.6
SDA74: J103.3, R216.2, U10.10
SDA75: J104.3, R218.2, U10.13
SDA76: J105.3, R220.2, U10.15
SDA77: J107.3, R224.2, U10.19
SDA78: J106.3, R222.2, U10.17
SDA79: J102.3, R214.2, U10.8

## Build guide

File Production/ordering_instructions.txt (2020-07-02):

panel size, 194x117mm
PCB thickness, 1.6mm
number of layers, 2
soldermask color, Red
silkscreen color, White
oz copper, 1oz
finish, HASL lead free
stencils, top
pcs per panel, 10
min trace width, 0.1778mm / 0.0070in
min drill size, 0.3810mm / 0.0150in

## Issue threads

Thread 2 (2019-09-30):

Double main Qwiic connector

aburio, 2019-09-30:
Any chance that a new version of the board appear with a double main Qwiic connector ?

The idea is to be able to chain multiple TCA9548A on one I2C bus.

If you need held, I can update the eagle files.

Thank you,
Arthur

nseidle, 2019-10-02:
What a good idea! If you feel like modifiying the eagle files, a PR would be much appreciated. We'll do a branch and then merge once a new version is released.

santaimpersonator, 2019-12-28:
@nseidle I updated the board and created a [pull request](https://github.com/sparkfun/Qwiic_Mux_TCA9548A/pull/3).

santaimpersonator, 2019-12-30:
@nseidle I reviewed the board layout with @oclyke and @AndyEngland521. The pull request should be good now. Feel free to close this issue when you are ready.

Burnich, 2019-12-31:
Thank you @santaimpersonator ! Working on this issue was on my to do, but you have been faster than me 👍

I reviewed the file on my side and everythings looks good to me.

santaimpersonator, 2020-07-02:
Product revision is live: https://www.sparkfun.com/products/16784

Closing issue.

Closed 2020-07-02.

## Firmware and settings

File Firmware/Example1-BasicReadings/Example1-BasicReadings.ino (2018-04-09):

/*
  Qwiic Mux Shield - PCA9548A/TCA9548A Basic Control
  By: Nathan Seidle
  SparkFun Electronics
  Date: March 30th, 2017
  License: This code is public domain but you buy me a beer if you use this and we meet someday (Beerware license).

  Reads two MMA8452Q accelerometers that have the same I2C address.
  You can read the MMA8452Q hookup guide and get the library from https://learn.sparkfun.com/tutorials/mma8452q-accelerometer-breakout-hookup-guide

  The PCA9548A is a mux. This means when you enableMuxPort(2) then the SDA and SCL lines of the master (Arduino)
  are connected to port 2. Whatever I2C traffic you do, such as accel.init() will be communicated to whatever
  sensor you have on port 2. You don't need accel2.init() or accel5.init().

  Outputs two sets of XYZ acceleration

  Hardware Connections:
  Attach the Qwiic Mux Shield to your RedBoard or Uno.
  Plug two Qwiic MMA8452Q breakout boards into ports 0 and 1.
  Serial.print it out at 9600 baud to serial monitor.

*/

#include <Wire.h>
#include <SparkFun_MMA8452Q.h> // Includes the SFE_MMA8452Q library

MMA8452Q accel;

#define NUMBER_OF_SENSORS 1

const byte portNumber = 4;

void setup()
{
  Serial.begin(9600);
  Serial.println("Qwiic Mux Shield Read Example");

  Wire.begin();

  enableMuxPort(portNumber); //Tell mux to connect to port X
  accel.init(); //Init the sensor connected to this port
  disableMuxPort(portNumber);

  Serial.println("Mux Shield online");
}

void loop()
{
  enableMuxPort(portNumber); //Tell mux to connect to this port, and this port only

  if (accel.available())
  {
    accel.read();

    Serial.print("Accel ");
    Serial.print(portNumber);
    Serial.print(": ");
    Serial.print(accel.cx, 2);
    Serial.print(" ");
    Serial.print(accel.cy, 2);
    Serial.print(" ");
    Serial.print(accel.cz, 2);
    Serial.print(" ");

    Serial.println(); // Print new line every time.
  }

  disableMuxPort(portNumber); //Tell mux to disconnect from this port

  delay(1); //Wait for next reading
}

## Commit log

2018-04-17 Post design Review Changes
    [Qwiic Mux.brd, Qwiic Mux.sch]
2018-05-23 checklist changes
    [Qwiic Mux.brd, Qwiic Mux.sch]
2018-05-29 Updated Qwiic connector
    [Qwiic Mux.brd, Qwiic Mux.sch]
2018-05-30 created panel v10
    [Qwiic Mux-Panel_v10-Panel.brd]
2019-12-28 Update Board
    Add second "Main" Qwiic connector
    [Qwiic Mux.brd, Qwiic Mux.sch]
2019-12-30 Fix routing and version numbering
    [Qwiic Mux.brd, Qwiic Mux.sch]
2020-02-28 Update Qwiic Mux.brd
    Fix trace thickness
    [Qwiic Mux.brd]
2020-05-17 Update Qwiic label. Update labels on ADR and RESET pins.
    [Qwiic Mux.brd, Qwiic Mux.sch]
2020-05-19 creating panel v11
    [Qwiic Mux-Panel.GBL, Qwiic Mux-Panel.GBO, Qwiic Mux-Panel.GBP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]

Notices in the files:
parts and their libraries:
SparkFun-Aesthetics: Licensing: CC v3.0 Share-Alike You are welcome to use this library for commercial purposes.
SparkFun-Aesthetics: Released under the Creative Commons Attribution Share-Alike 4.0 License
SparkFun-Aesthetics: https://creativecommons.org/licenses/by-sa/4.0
